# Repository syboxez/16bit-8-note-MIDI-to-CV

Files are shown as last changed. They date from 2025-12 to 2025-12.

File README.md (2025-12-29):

Multichannel MIDI to CV module by Craig Barnes and Andreas Oswald Hierzenberger
- Original project here: https://github.com/craigyjp/16bit-8-note-MIDI-to-CV

This project was originally designed as a proof of concept of an 8 channel 16-bit MIDI to CV module with autotune. This project has since been essentially deprecated in favor of Craig Branes's future projects, which you can find on his GitHub: https://github.com/craigyjp. Please do not ask for support with this project.

The KiCad schematics and Eurorack PCB can be found in the Hardware/schematics/kicad directory. Note that while the LFO module is not a part of the PCB, the schematics are still available in the same directory. The schematics include a change from +-15v to +-12v. This requires a 16 pin Eurorack power connector that includes a +5v power rail. A micro SD card should be inserted into the Teensy 4.1 to save settings.

The panel board uses DE-9 connectors as an easier patching method for polyphonic Eurorack-style patching up to eight voices. Converting between this connector and standard 3.5mm TS connectors is as simple as making a passive cable to do so. The pinout is as such:
Pins 1-8: Channels 1-8 respectively
Pin 9: Ground
- A PCB to make making an adapter more convenient is available here: https://gitlab.com/syboxez/de9-to-ts

All resistors and capacitors are 0805 SMD components, so this board can still be hand soldered.

TODO:
- Panel
- Build and Test

This project is licensed under the GNU GPL v3. A copy of the license is included in LICENSE.md. When redistributing, Craig Barnes and Andreas Oswald Hierzenberger MUST be mentioned, and a copy of the license must be included.

Original README below:
---

# 16bit-8-note-MIDI-to-CV

* Collaboration with Andreas Oswald "MrsColumbo" Hierzenberger

Newer version of my old 6 note poly CV converter, this time it uses 16 bit DACs and has the facility for autotune (not yet implemented). 

Using a teensy 4.1, the CV's, Pitchbend, CC, gates and triggers will all need some level conversion in hardware which I've covered in the schematic PDF. I've used matching 12k/36k resistors on the CV DAC level converters to give 4x conversion and this gives 1v/octave, Velocity uses 10k/10k for 2x conversion for 0-5v velocity range.

* The triggers and gates are currently +5v.
* 16 CV ouputs in 2 banks of 8 for osc1 & osc2 configurations
* 8 filter CV outputs
* 8 velocity CV outputs
* 8 gate outputs
* 8 trigger outputs
* Pitchbend, channel aftertouch and CC outputs
* Sustain pedal support over MIDI
* MIDI Channel selection or Omni
* Poly1, Poly2, Unison & Mono modes with note priority modes
* Polyphony variable from 2-8 notes, 1 note not required as you already have unison and mono.
* Transpose Mode +/- one Octave
* Octave shift 0 to -3 Octaves to give 0V on bottom C
* Oscillator 2 detune (CV outputs 9-16)
* Oscillator 2 interval settings 0-12 semitones (CV outputs 9-16)
* Up/Down/Select buttons for menu
* USB MIDI Host support as well as 5 pin DIN

# During the testing all the controls were done manually with pots and buttons, but to be integrated into a polysynth these functions need to be controlled over MIDI.

* MIDI CC numbers used to control functions

* CC 01  Modulation Wheel 0-12
* CC 14  VCO_B Interval. 0-127 (0-12 semitones)
* CC 15  VCO_B Detune. 0-12
* CC 16  PitchBend Depth. 0-127 (0-12 seimitones)
* CC 17  FM Mod Wheel Depth. 0-127
* CC 18  TM Mod Wheel Depth. 0-127
* CC 19  FM Aftertouch Depth. 0-127
* CC 20  TM Aftertouch Depth. 0-127
* CC 21  VCO_A Octave switch. (0-127) -1, 0, +1
* CC 22  VCO_B Octave switch. (0-127) -1, 0, +1
* CC 64  Sustain. 0-127  off < 63, on > 63
* CC 121 Start Autotune Routine.  start > 63
* CC 127 Keyboard Mode  0-127, Poly1, Poly2, Unison T,B,L, Mono T, B, L

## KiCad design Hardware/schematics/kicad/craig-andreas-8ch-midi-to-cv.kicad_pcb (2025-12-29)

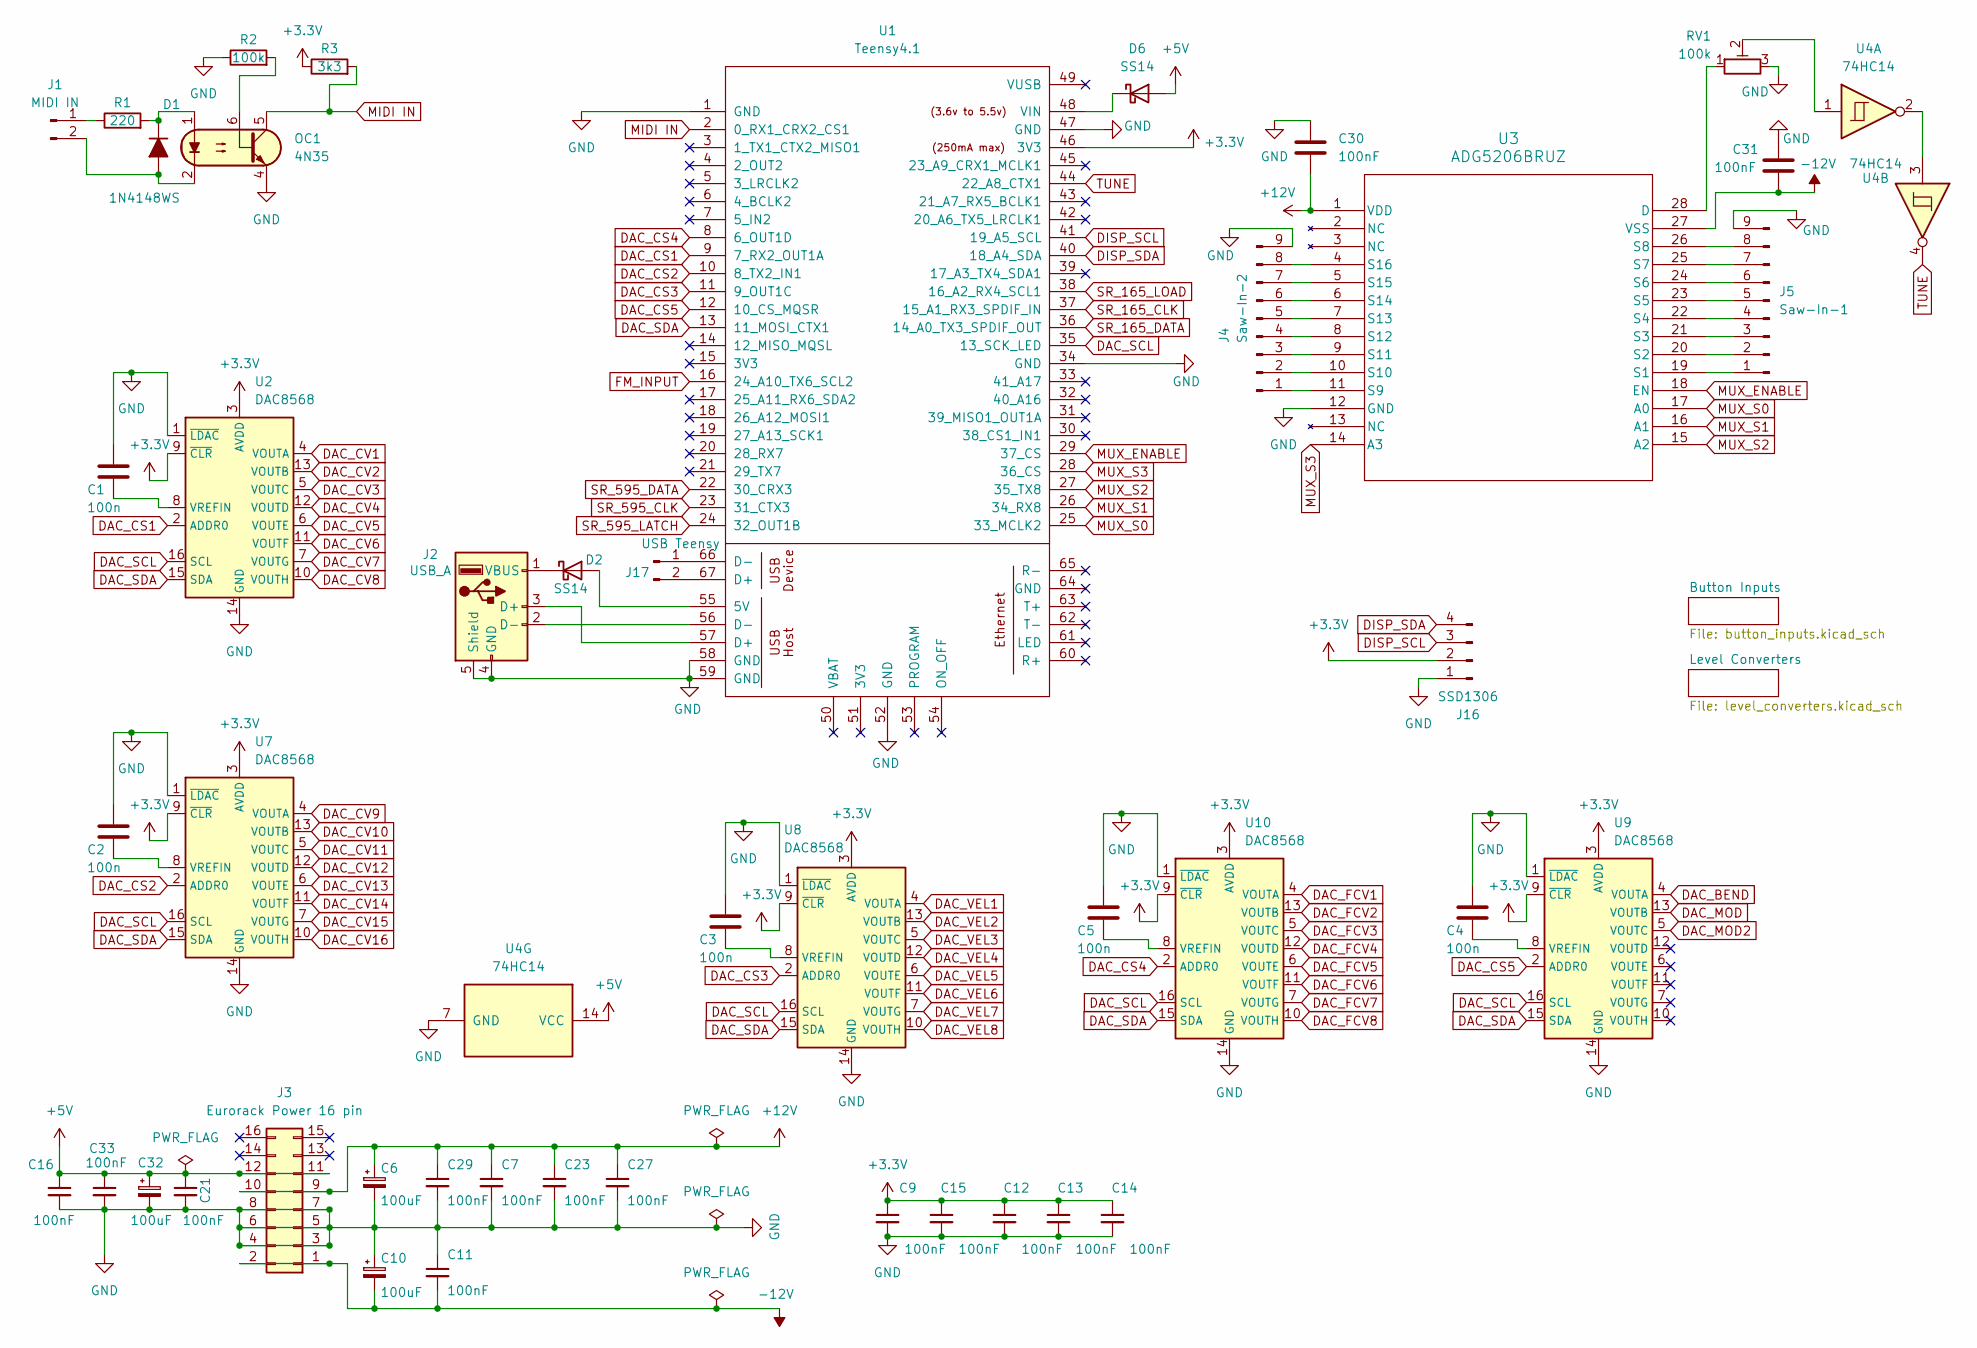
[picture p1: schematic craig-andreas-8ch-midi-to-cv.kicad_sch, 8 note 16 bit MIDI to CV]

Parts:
C1, C2, C3, C4, C5: 100n; C_0805_2012Metric_Pad1.18x1.45mm_HandSolder
C6, C10, C32: 100uF; CP_Radial_D8.0mm_P3.50mm
C7, C9, C11, C12, C13, C14, C15, C16, C21, C23, C27, C29, C30, C31, C33: 100nF; C_0805_2012Metric_Pad1.18x1.45mm_HandSolder
D1: 1N4148WS; D_SOD-323_HandSoldering
D2, D6: SS14; D_SMA_Handsoldering
J1: MIDI IN; JST_XH_B2B-XH-A_1x02_P2.50mm_Vertical
J2: USB_A; JST_XH_B3B-XH-A_1x03_P2.50mm_Vertical
J3: Eurorack Power 16 pin; IDC-Header_2x08_P2.54mm_Vertical
J4: Saw-In-2; JST_XH_B9B-XH-A_1x09_P2.50mm_Vertical
J5: Saw-In-1; JST_XH_B9B-XH-A_1x09_P2.50mm_Vertical
J16: SSD1306; JST_XH_B4B-XH-A_1x04_P2.50mm_Vertical
J17: USB Teensy; JST_XH_B2B-XH-A_1x02_P2.50mm_Vertical
OC1: 4N35; DIP-6_W7.62mm_LongPads
R1: 220; R_0805_2012Metric_Pad1.15x1.40mm_HandSolder
R2: 100k; R_0805_2012Metric_Pad1.15x1.40mm_HandSolder
R3: 3k3; R_0805_2012Metric_Pad1.15x1.40mm_HandSolder
RV1: 100k; Potentiometer_Runtron_RM-065_Vertical
U1: Teensy4.1; Teensy41
U2, U7, U8, U9, U10: DAC8568; TSSOP-16_4.4x5mm_P0.65mm
U3: ADG5206BRUZ; RU_28_ADI
U4: 74HC14; SOIC-14_3.9x8.7mm_P1.27mm

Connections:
+3.3V: C9.1, C12.1, C13.1, C14.1, C15.1, J16.2, R3.1, U1.46 (3V3), U2.3 (AVDD), U2.9 (~CLR), U7.3 (AVDD), U7.9 (~CLR), U8.3 (AVDD), U8.9 (~CLR), U9.3 (AVDD), U9.9 (~CLR), U10.3 (AVDD), U10.9 (~CLR); also elsewhere on the board
+5V: C16.1, C21.1, C32.1, C33.1, D6.2 (A), J3.11, J3.12, U4.14 (VCC); also elsewhere on the board
+12V: C6.1, C7.1, C23.1, C27.1, C29.1, C30.2, J3.9, J3.10, U3.1 (VDD); also elsewhere on the board
-12V: C10.2, C11.2, C31.1, J3.1, J3.2, U3.27 (VSS)
DAC_BEND: U9.4 (VOUTA); also elsewhere on the board
DAC_CS1: U1.9 (7_RX2_OUT1A), U2.2 (ADDR0)
DAC_CS2: U1.10 (8_TX2_IN1), U7.2 (ADDR0)
DAC_CS3: U1.11 (9_OUT1C), U8.2 (ADDR0)
DAC_CS4: U1.8 (6_OUT1D), U10.2 (ADDR0)
DAC_CS5: U1.12 (10_CS_MQSR), U9.2 (ADDR0)
DAC_CV1: U2.4 (VOUTA); also elsewhere on the board
DAC_CV2: U2.13 (VOUTB); also elsewhere on the board
DAC_CV3: U2.5 (VOUTC); also elsewhere on the board
DAC_CV4: U2.12 (VOUTD); also elsewhere on the board
DAC_CV5: U2.6 (VOUTE); also elsewhere on the board
DAC_CV6: U2.11 (VOUTF); also elsewhere on the board
DAC_CV7: U2.7 (VOUTG); also elsewhere on the board
DAC_CV8: U2.10 (VOUTH); also elsewhere on the board
DAC_CV9: U7.4 (VOUTA); also elsewhere on the board
DAC_CV10: U7.13 (VOUTB); also elsewhere on the board
DAC_CV11: U7.5 (VOUTC); also elsewhere on the board
DAC_CV12: U7.12 (VOUTD); also elsewhere on the board
DAC_CV13: U7.6 (VOUTE); also elsewhere on the board
DAC_CV14: U7.11 (VOUTF); also elsewhere on the board
DAC_CV15: U7.7 (VOUTG); also elsewhere on the board
DAC_CV16: U7.10 (VOUTH); also elsewhere on the board
DAC_FCV1: U10.4 (VOUTA); also elsewhere on the board
DAC_FCV2: U10.13 (VOUTB); also elsewhere on the board
DAC_FCV3: U10.5 (VOUTC); also elsewhere on the board
DAC_FCV4: U10.12 (VOUTD); also elsewhere on the board
DAC_FCV5: U10.6 (VOUTE); also elsewhere on the board
DAC_FCV6: U10.11 (VOUTF); also elsewhere on the board
DAC_FCV7: U10.7 (VOUTG); also elsewhere on the board
DAC_FCV8: U10.10 (VOUTH); also elsewhere on the board
DAC_MOD: U9.13 (VOUTB); also elsewhere on the board
DAC_MOD2: U9.5 (VOUTC); also elsewhere on the board
DAC_SCL: U1.35 (13_SCK_LED), U2.16 (SCL), U7.16 (SCL), U8.16 (SCL), U9.16 (SCL), U10.16 (SCL)
DAC_SDA: U1.13 (11_MOSI_CTX1), U2.15 (SDA), U7.15 (SDA), U8.15 (SDA), U9.15 (SDA), U10.15 (SDA)
DAC_VEL1: U8.4 (VOUTA); also elsewhere on the board
DAC_VEL2: U8.13 (VOUTB); also elsewhere on the board
DAC_VEL3: U8.5 (VOUTC); also elsewhere on the board
DAC_VEL4: U8.12 (VOUTD); also elsewhere on the board
DAC_VEL5: U8.6 (VOUTE); also elsewhere on the board
DAC_VEL6: U8.11 (VOUTF); also elsewhere on the board
DAC_VEL7: U8.7 (VOUTG); also elsewhere on the board
DAC_VEL8: U8.10 (VOUTH); also elsewhere on the board
DISP_SCL: J16.3, U1.41 (19_A5_SCL)
DISP_SDA: J16.4, U1.40 (18_A4_SDA)
FM_INPUT: U1.16 (24_A10_TX6_SCL2)
GND: C1.1, C2.1, C3.1, C4.1, C5.1, C6.2, C7.2, C9.2, C10.1, C11.1, C12.2, C13.2, C14.2, C15.2, C16.2, C21.2, C23.2, C27.2, C29.2, C30.1, C31.2, C32.2, C33.2, J2.4 (GND), J2.5 (Shield), J3.3, J3.4, J3.5, J3.6, J3.7, J3.8, J4.9, J5.9, J16.1, OC1.4, R2.1, RV1.3, U1.1 (GND), U1.34 (GND), U1.47 (GND), U1.52 (GND), U1.58 (GND), U1.59 (GND), U2.1 (~LDAC), U2.14 (GND), U3.12 (GND), U4.7 (GND), U7.1 (~LDAC), U7.14 (GND), U8.1 (~LDAC), U8.14 (GND), U9.1 (~LDAC), U9.14 (GND), U10.1 (~LDAC), U10.14 (GND); also elsewhere on the board
MIDI IN: OC1.5, R3.2, U1.2 (0_RX1_CRX2_CS1)
MUX_ENABLE: U1.29 (37_CS), U3.18 (EN)
MUX_S0: U1.25 (33_MCLK2), U3.17 (A0)
MUX_S1: U1.26 (34_RX8), U3.16 (A1)
MUX_S2: U1.27 (35_TX8), U3.15 (A2)
MUX_S3: U1.28 (36_CS), U3.14 (A3)
unnamed: D1.2 (A), J1.2, OC1.2
unnamed: D1.1 (K), OC1.1, R1.2
unnamed: D2.2 (A), U1.55 (5V)
unnamed: D2.1 (K), J2.1 (VBUS)
unnamed: D6.1 (K), U1.48 (VIN)
unnamed: J1.1, R1.1
unnamed: J2.3 (D+), U1.57 (D+)
unnamed: J2.2 (D-), U1.56 (D-)
unnamed: J4.1, U3.11 (S9)
unnamed: J4.2, U3.10 (S10)
unnamed: J4.3, U3.9 (S11)
unnamed: J4.4, U3.8 (S12)
unnamed: J4.5, U3.7 (S13)
unnamed: J4.6, U3.6 (S14)
unnamed: J4.7, U3.5 (S15)
unnamed: J4.8, U3.4 (S16)
unnamed: J5.1, U3.19 (S1)
unnamed: J5.2, U3.20 (S2)
unnamed: J5.3, U3.21 (S3)
unnamed: J5.4, U3.22 (S4)
unnamed: J5.5, U3.23 (S5)
unnamed: J5.6, U3.24 (S6)
unnamed: J5.7, U3.25 (S7)
unnamed: J5.8, U3.26 (S8)
unnamed: J17.1, U1.66 (D-)
unnamed: J17.2, U1.67 (D+)
unnamed: OC1.6, R2.2
unnamed: RV1.2, U4.1
unnamed: C1.2, U2.8 (VREFIN)
unnamed: RV1.1, U3.28 (D)
unnamed: U4.2, U4.3
unnamed: C2.2, U7.8 (VREFIN)
unnamed: C3.2, U8.8 (VREFIN)
unnamed: C4.2, U9.8 (VREFIN)
unnamed: C5.2, U10.8 (VREFIN)
SR_165_CLK: U1.37 (15_A1_RX3_SPDIF_IN); also elsewhere on the board
SR_165_DATA: U1.36 (14_A0_TX3_SPDIF_OUT); also elsewhere on the board
SR_165_LOAD: U1.38 (16_A2_RX4_SCL1); also elsewhere on the board
SR_595_CLK: U1.23 (31_CTX3); also elsewhere on the board
SR_595_DATA: U1.22 (30_CRX3); also elsewhere on the board
SR_595_LATCH: U1.24 (32_OUT1B); also elsewhere on the board
TUNE: U1.44 (22_A8_CTX1), U4.4

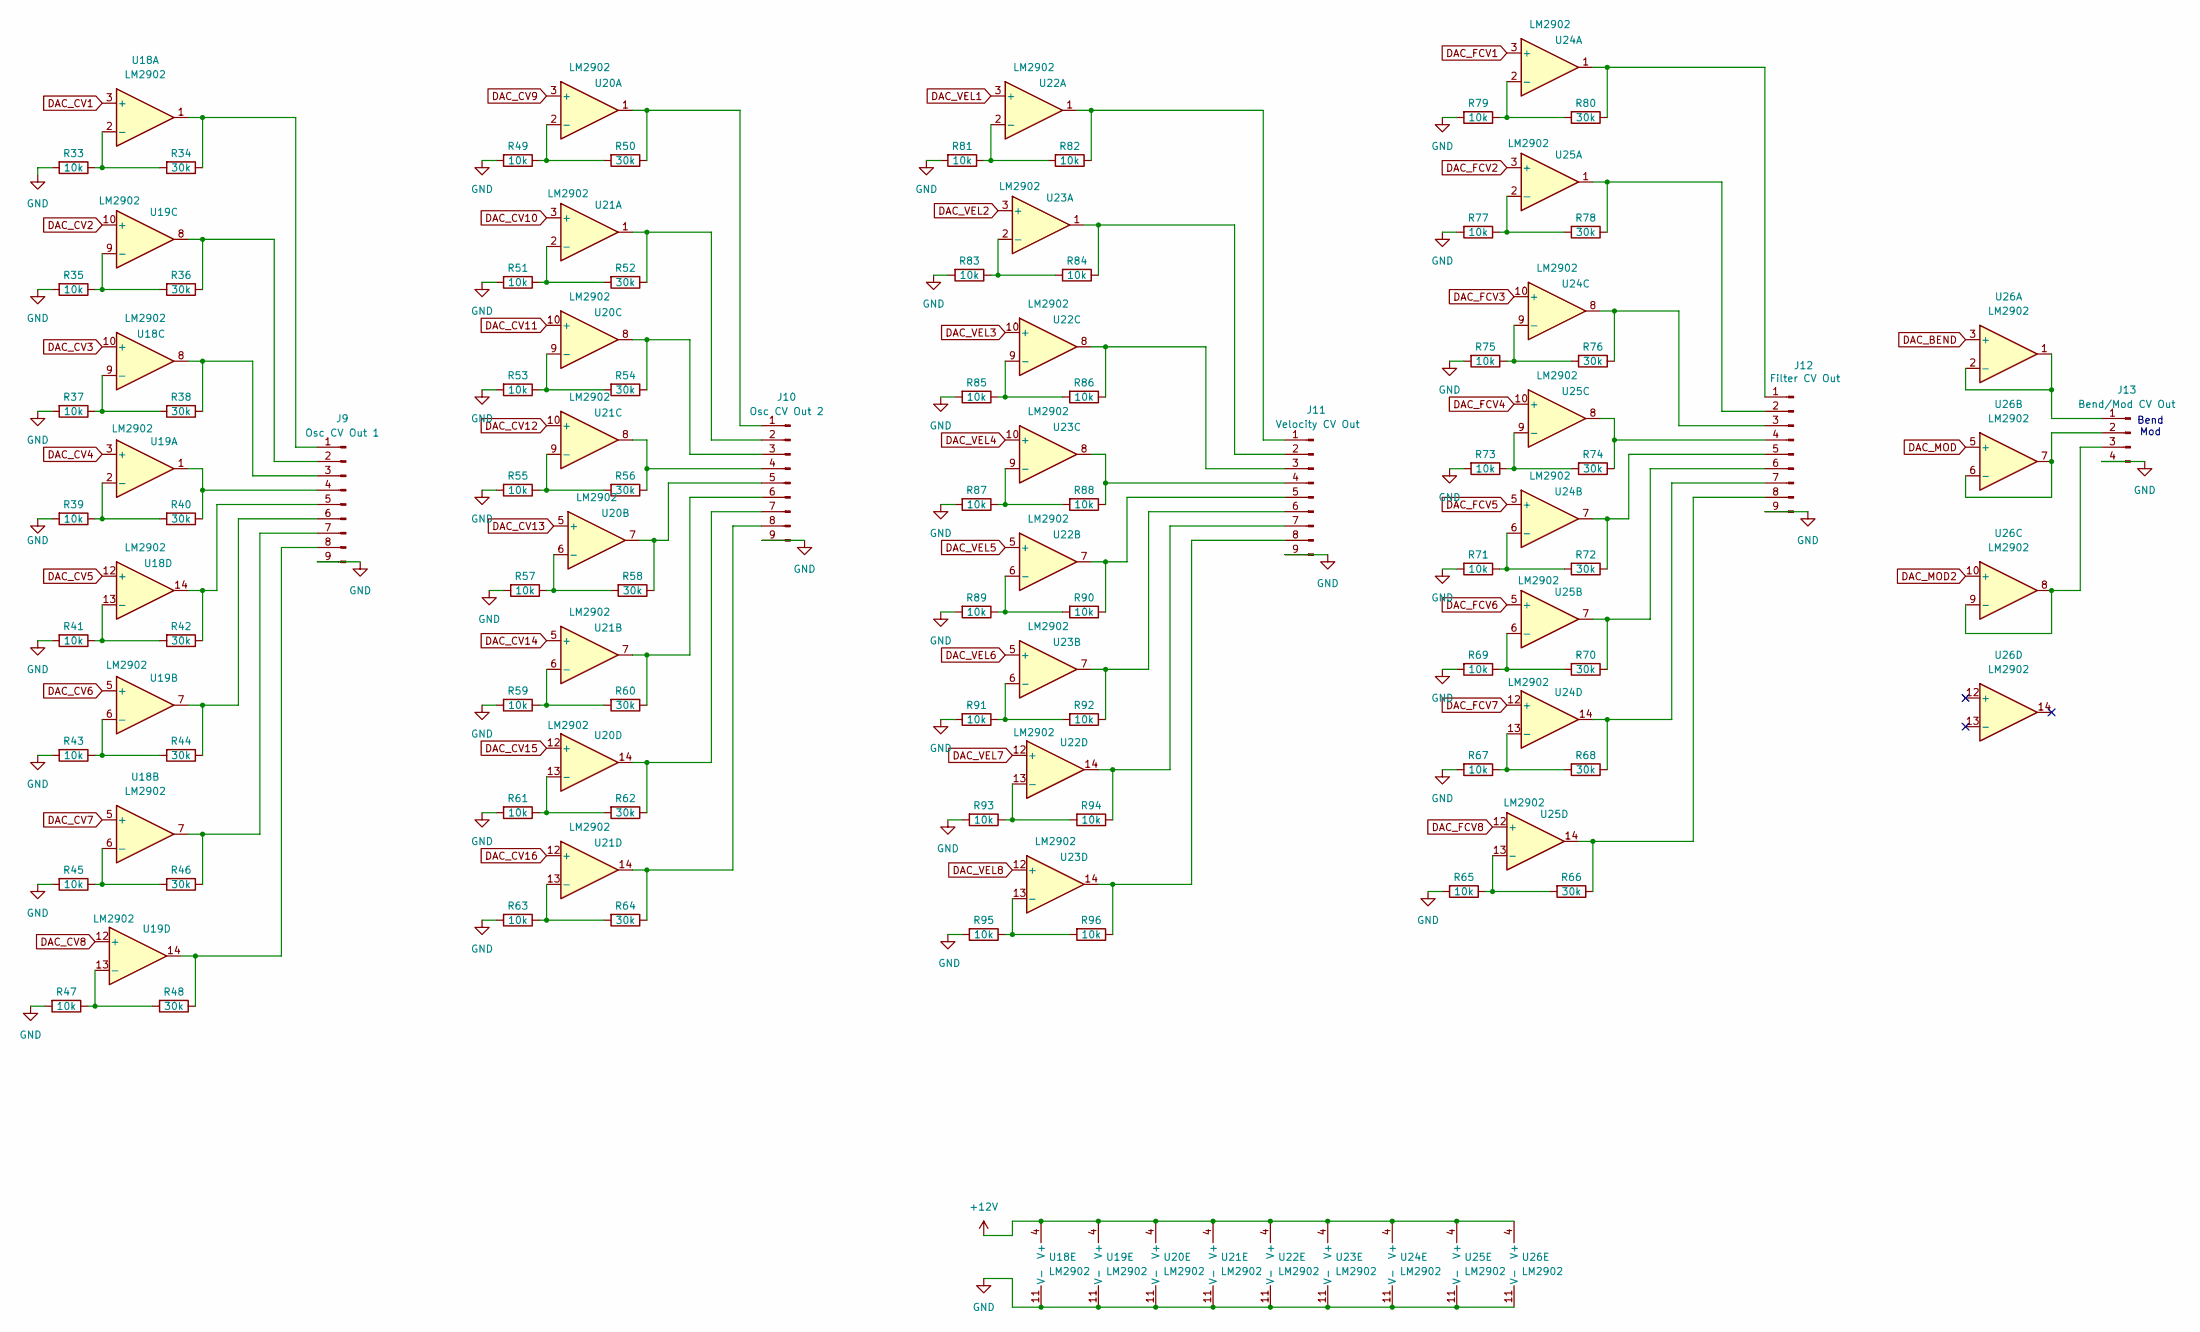
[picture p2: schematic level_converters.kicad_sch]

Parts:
J9: Osc CV Out 1; IDC-Header_2x05_P2.54mm_Vertical
J10: Osc CV Out 2; IDC-Header_2x05_P2.54mm_Vertical
J11: Velocity CV Out; IDC-Header_2x05_P2.54mm_Vertical
J12: Filter CV Out; JST_XH_B9B-XH-A_1x09_P2.50mm_Vertical
J13: Bend/Mod CV Out; JST_XH_B4B-XH-A_1x04_P2.50mm_Vertical
R33, R35, R37, R39, R41, R43, R45, R47, R49, R51, R53, R55, R57, R59, R61, R63, R65, R67, R69, R71, R73, R75, R77, R79, R81, R82, R83, R84, R85, R86, R87, R88, R89, R90, R91, R92, R93, R94, R95, R96: 10k; R_0805_2012Metric_Pad1.15x1.40mm_HandSolder
R34, R36, R38, R40, R42, R44, R46, R48, R50, R52, R54, R56, R58, R60, R62, R64, R66, R68, R70, R72, R74, R76, R78, R80: 30k; R_0805_2012Metric_Pad1.15x1.40mm_HandSolder
U18, U19, U20, U21, U22, U23, U24, U25, U26: LM2902; SOIC-14_3.9x8.7mm_P1.27mm

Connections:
+12V: U18.4 (V+), U19.4 (V+), U20.4 (V+), U21.4 (V+), U22.4 (V+), U23.4 (V+), U24.4 (V+), U25.4 (V+), U26.4 (V+); also elsewhere on the board
DAC_BEND: U26.3 (+); also elsewhere on the board
DAC_CV1: U18.3 (+); also elsewhere on the board
DAC_CV2: U19.10 (+); also elsewhere on the board
DAC_CV3: U18.10 (+); also elsewhere on the board
DAC_CV4: U19.3 (+); also elsewhere on the board
DAC_CV5: U18.12 (+); also elsewhere on the board
DAC_CV6: U19.5 (+); also elsewhere on the board
DAC_CV7: U18.5 (+); also elsewhere on the board
DAC_CV8: U19.12 (+); also elsewhere on the board
DAC_CV9: U20.3 (+); also elsewhere on the board
DAC_CV10: U21.3 (+); also elsewhere on the board
DAC_CV11: U20.10 (+); also elsewhere on the board
DAC_CV12: U21.10 (+); also elsewhere on the board
DAC_CV13: U20.5 (+); also elsewhere on the board
DAC_CV14: U21.5 (+); also elsewhere on the board
DAC_CV15: U20.12 (+); also elsewhere on the board
DAC_CV16: U21.12 (+); also elsewhere on the board
DAC_FCV1: U24.3 (+); also elsewhere on the board
DAC_FCV2: U25.3 (+); also elsewhere on the board
DAC_FCV3: U24.10 (+); also elsewhere on the board
DAC_FCV4: U25.10 (+); also elsewhere on the board
DAC_FCV5: U24.5 (+); also elsewhere on the board
DAC_FCV6: U25.5 (+); also elsewhere on the board
DAC_FCV7: U24.12 (+); also elsewhere on the board
DAC_FCV8: U25.12 (+); also elsewhere on the board
DAC_MOD: U26.5 (+); also elsewhere on the board
DAC_MOD2: U26.10 (+); also elsewhere on the board
DAC_VEL1: U22.3 (+); also elsewhere on the board
DAC_VEL2: U23.3 (+); also elsewhere on the board
DAC_VEL3: U22.10 (+); also elsewhere on the board
DAC_VEL4: U23.10 (+); also elsewhere on the board
DAC_VEL5: U22.5 (+); also elsewhere on the board
DAC_VEL6: U23.5 (+); also elsewhere on the board
DAC_VEL7: U22.12 (+); also elsewhere on the board
DAC_VEL8: U23.12 (+); also elsewhere on the board
GND: J9.9, J9.10, J10.9, J10.10, J11.9, J11.10, J12.9, J13.4, R33.2, R35.2, R37.2, R39.2, R41.2, R43.2, R45.2, R47.2, R49.2, R51.2, R53.2, R55.2, R57.2, R59.2, R61.2, R63.2, R65.2, R67.2, R69.2, R71.2, R73.2, R75.2, R77.2, R79.2, R81.2, R83.2, R85.2, R87.2, R89.2, R91.2, R93.2, R95.2, U18.11 (V-), U19.11 (V-), U20.11 (V-), U21.11 (V-), U22.11 (V-), U23.11 (V-), U24.11 (V-), U25.11 (V-), U26.11 (V-); also elsewhere on the board
unnamed: J9.1, R34.1, U18.1
unnamed: J9.2, R36.1, U19.8
unnamed: J9.3, R38.1, U18.8
unnamed: J9.4, R40.1, U19.1
unnamed: J9.5, R42.1, U18.14
unnamed: J9.6, R44.1, U19.7
unnamed: J9.7, R46.1, U18.7
unnamed: J9.8, R48.1, U19.14
unnamed: J10.1, R50.1, U20.1
unnamed: J10.2, R52.1, U21.1
unnamed: J10.3, R54.1, U20.8
unnamed: J10.4, R56.1, U21.8
unnamed: J10.5, R58.1, U20.7
unnamed: J10.6, R60.1, U21.7
unnamed: J10.7, R62.1, U20.14
unnamed: J10.8, R64.1, U21.14
unnamed: J11.1, R82.1, U22.1
unnamed: J11.2, R84.1, U23.1
unnamed: J11.3, R86.1, U22.8
unnamed: J11.4, R88.1, U23.8
unnamed: J11.5, R90.1, U22.7
unnamed: J11.6, R92.1, U23.7
unnamed: J11.7, R94.1, U22.14
unnamed: J11.8, R96.1, U23.14
unnamed: J12.1, R80.1, U24.1
unnamed: J12.2, R78.1, U25.1
unnamed: J12.3, R76.1, U24.8
unnamed: J12.4, R74.1, U25.8
unnamed: J12.5, R72.1, U24.7
unnamed: J12.6, R70.1, U25.7
unnamed: J12.7, R68.1, U24.14
unnamed: J12.8, R66.1, U25.14
unnamed: J13.1, U26.1, U26.2 (-)
unnamed: J13.2, U26.6 (-), U26.7
unnamed: J13.3, U26.8, U26.9 (-)
unnamed: R33.1, R34.2, U18.2 (-)
unnamed: R45.1, R46.2, U18.6 (-)
unnamed: R37.1, R38.2, U18.9 (-)
unnamed: R41.1, R42.2, U18.13 (-)
unnamed: R39.1, R40.2, U19.2 (-)
unnamed: R43.1, R44.2, U19.6 (-)
unnamed: R35.1, R36.2, U19.9 (-)
unnamed: R47.1, R48.2, U19.13 (-)
unnamed: R49.1, R50.2, U20.2 (-)
unnamed: R57.1, R58.2, U20.6 (-)
unnamed: R53.1, R54.2, U20.9 (-)
unnamed: R61.1, R62.2, U20.13 (-)
unnamed: R51.1, R52.2, U21.2 (-)
unnamed: R59.1, R60.2, U21.6 (-)
unnamed: R55.1, R56.2, U21.9 (-)
unnamed: R63.1, R64.2, U21.13 (-)
unnamed: R81.1, R82.2, U22.2 (-)
unnamed: R89.1, R90.2, U22.6 (-)
unnamed: R85.1, R86.2, U22.9 (-)
unnamed: R93.1, R94.2, U22.13 (-)
unnamed: R83.1, R84.2, U23.2 (-)
unnamed: R91.1, R92.2, U23.6 (-)
unnamed: R87.1, R88.2, U23.9 (-)
unnamed: R95.1, R96.2, U23.13 (-)
unnamed: R79.1, R80.2, U24.2 (-)
unnamed: R71.1, R72.2, U24.6 (-)
unnamed: R75.1, R76.2, U24.9 (-)
unnamed: R67.1, R68.2, U24.13 (-)
unnamed: R77.1, R78.2, U25.2 (-)
unnamed: R69.1, R70.2, U25.6 (-)
unnamed: R73.1, R74.2, U25.9 (-)
unnamed: R65.1, R66.2, U25.13 (-)

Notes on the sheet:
Bend Mod

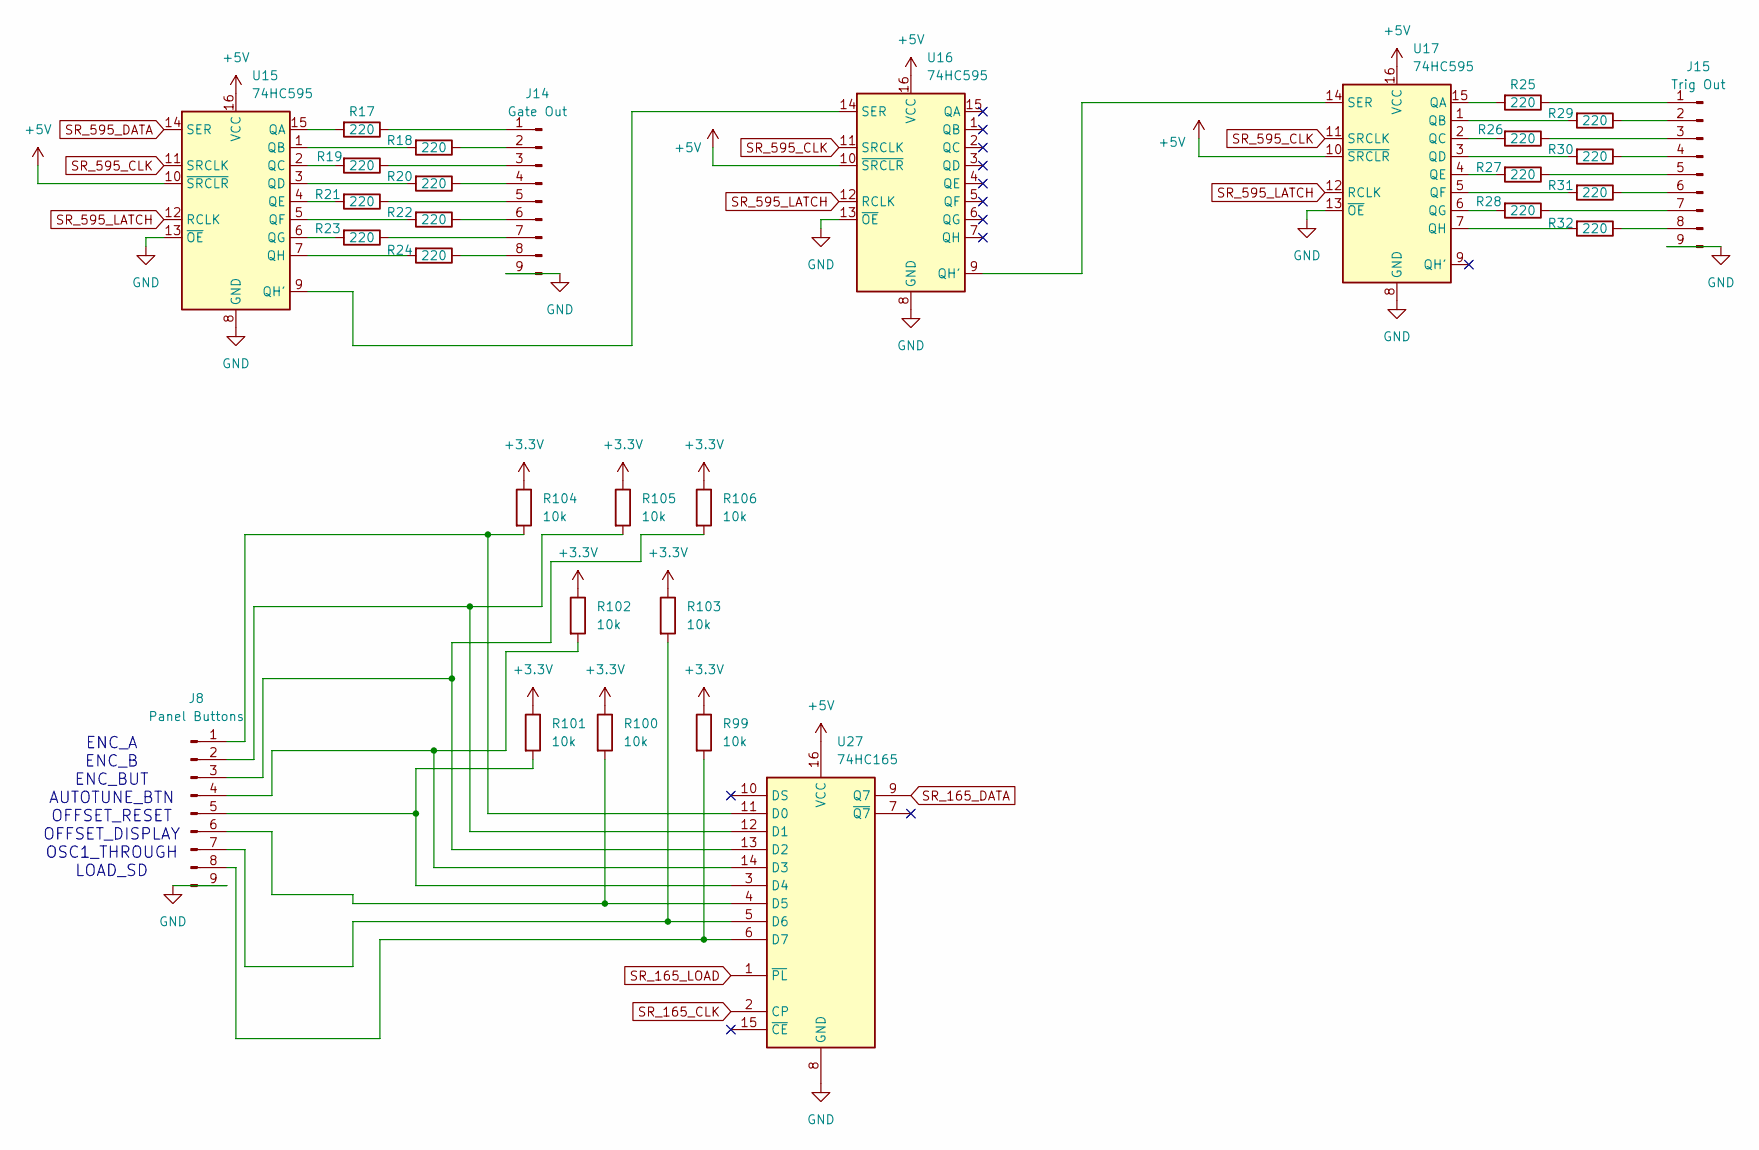
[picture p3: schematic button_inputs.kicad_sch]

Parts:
J8: Panel Buttons; JST_XH_B9B-XH-A_1x09_P2.50mm_Vertical
J14: Gate Out; JST_XH_B9B-XH-A_1x09_P2.50mm_Vertical
J15: Trig Out; JST_XH_B9B-XH-A_1x09_P2.50mm_Vertical
R17, R18, R19, R20, R21, R22, R23, R24, R25, R26, R27, R28, R29, R30, R31, R32: 220; R_0805_2012Metric_Pad1.15x1.40mm_HandSolder
R99, R100, R101, R102, R103, R104, R105, R106: 10k; R_0805_2012Metric_Pad1.15x1.40mm_HandSolder
U15, U16, U17: 74HC595; SOIC-16_3.9x9.9mm_P1.27mm
U27: 74HC165; SOIC-16_3.9x9.9mm_P1.27mm

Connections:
+3.3V: R99.1, R100.1, R101.1, R102.1, R103.1, R104.1, R105.1, R106.1; also elsewhere on the board
+5V: U15.10 (~SRCLR), U15.16 (VCC), U16.10 (~SRCLR), U16.16 (VCC), U17.10 (~SRCLR), U17.16 (VCC), U27.16 (VCC); also elsewhere on the board
GND: J8.9, J14.9, J15.9, U15.8 (GND), U15.13 (~OE), U16.8 (GND), U16.13 (~OE), U17.8 (GND), U17.13 (~OE), U27.8 (GND); also elsewhere on the board
unnamed: J8.1, R104.2, U27.11 (D0)
unnamed: J8.2, R105.2, U27.12 (D1)
unnamed: J8.3, R106.2, U27.13 (D2)
unnamed: J8.4, R102.2, U27.14 (D3)
unnamed: J8.5, R101.2, U27.3 (D4)
unnamed: J8.6, R100.2, U27.4 (D5)
unnamed: J8.7, R103.2, U27.5 (D6)
unnamed: J8.8, R99.2, U27.6 (D7)
unnamed: J14.1, R17.1
unnamed: J14.2, R18.1
unnamed: J14.3, R19.1
unnamed: J14.4, R20.1
unnamed: J14.5, R21.1
unnamed: J14.6, R22.1
unnamed: J14.7, R23.1
unnamed: J14.8, R24.1
unnamed: J15.1, R25.1
unnamed: J15.2, R29.1
unnamed: J15.3, R26.1
unnamed: J15.4, R30.1
unnamed: J15.5, R27.1
unnamed: J15.6, R31.1
unnamed: J15.7, R28.1
unnamed: J15.8, R32.1
unnamed: R17.2, U15.15 (QA)
unnamed: R18.2, U15.1 (QB)
unnamed: R19.2, U15.2 (QC)
unnamed: R20.2, U15.3 (QD)
unnamed: R21.2, U15.4 (QE)
unnamed: R22.2, U15.5 (QF)
unnamed: R23.2, U15.6 (QG)
unnamed: U15.9 (QH'), U16.14 (SER)
unnamed: R24.2, U15.7 (QH)
unnamed: U16.9 (QH'), U17.14 (SER)
unnamed: R25.2, U17.15 (QA)
unnamed: R29.2, U17.1 (QB)
unnamed: R26.2, U17.2 (QC)
unnamed: R30.2, U17.3 (QD)
unnamed: R27.2, U17.4 (QE)
unnamed: R31.2, U17.5 (QF)
unnamed: R28.2, U17.6 (QG)
unnamed: R32.2, U17.7 (QH)
SR_165_CLK: U27.2 (CP); also elsewhere on the board
SR_165_DATA: U27.9 (Q7); also elsewhere on the board
SR_165_LOAD: U27.1 (~PL); also elsewhere on the board
SR_595_CLK: U15.11 (SRCLK), U16.11 (SRCLK), U17.11 (SRCLK); also elsewhere on the board
SR_595_DATA: U15.14 (SER); also elsewhere on the board
SR_595_LATCH: U15.12 (RCLK), U16.12 (RCLK), U17.12 (RCLK); also elsewhere on the board

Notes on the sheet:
ENC_A ENC_B ENC_BUT AUTOTUNE_BTN OFFSET_RESET OFFSET_DISPLAY OSC1_THROUGH LOAD_SD

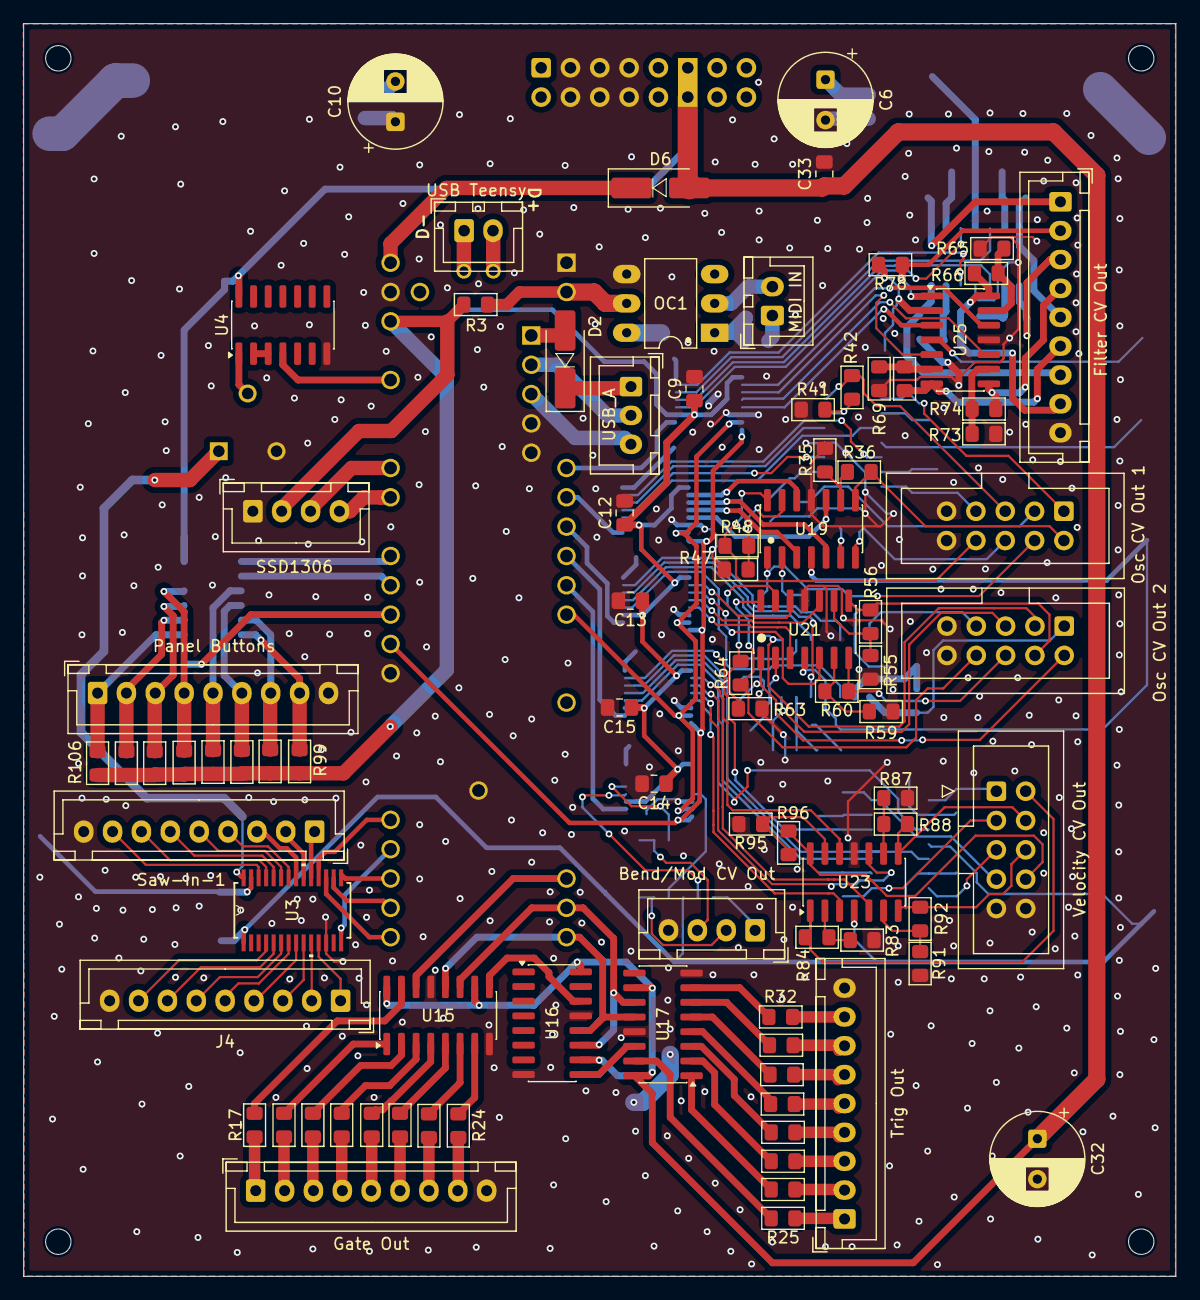
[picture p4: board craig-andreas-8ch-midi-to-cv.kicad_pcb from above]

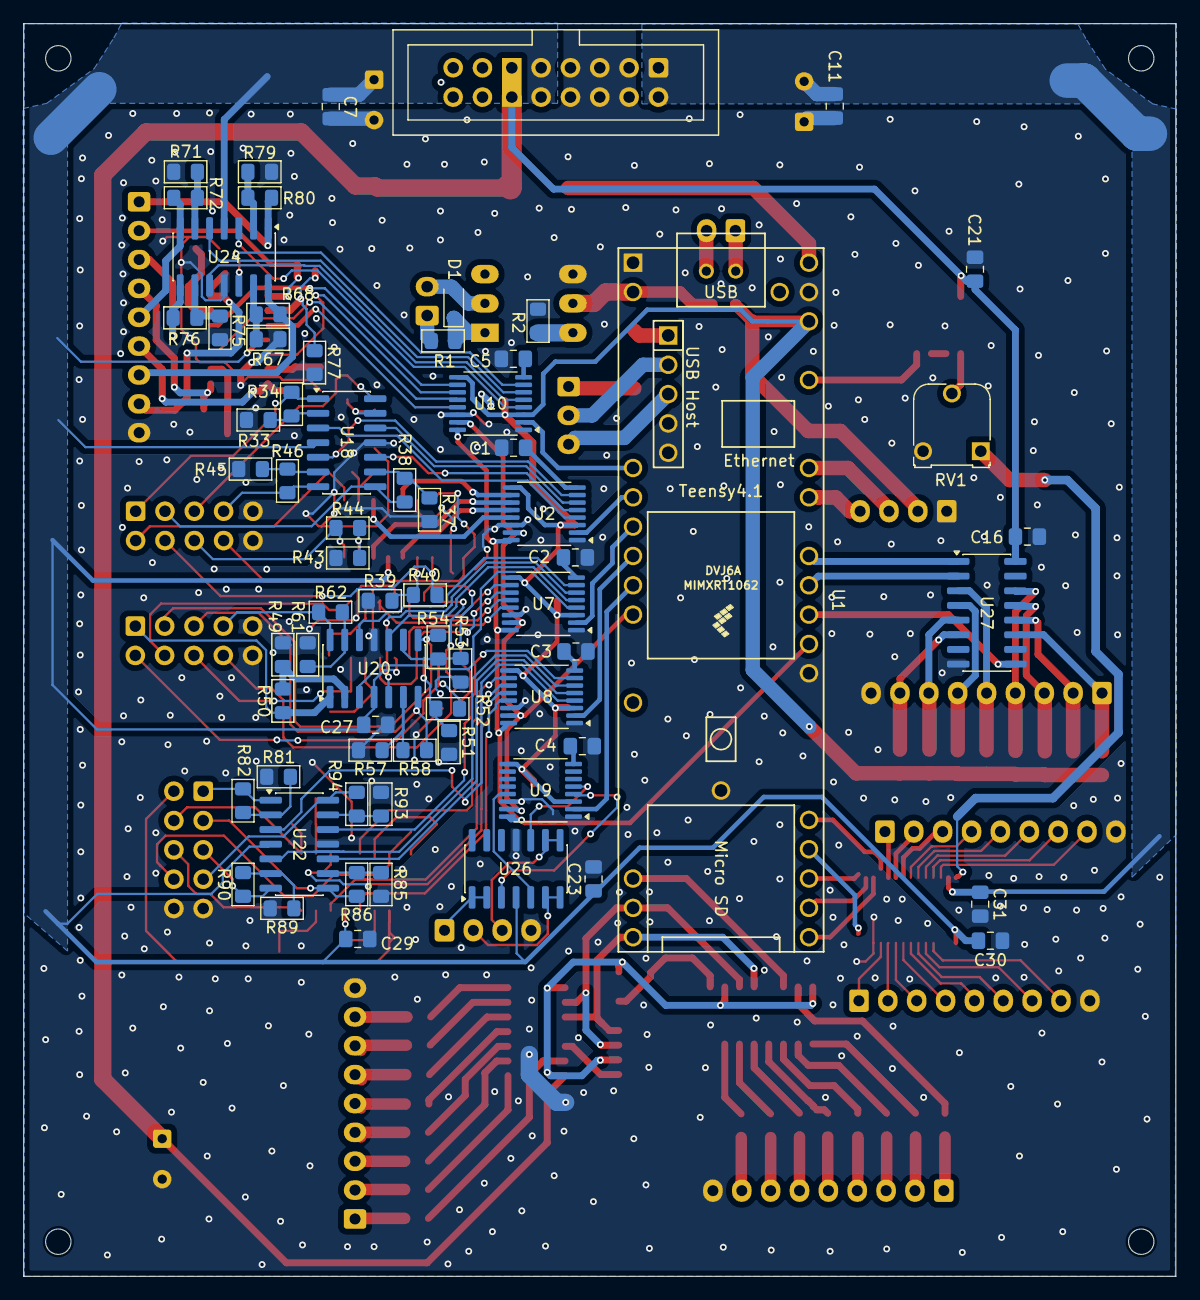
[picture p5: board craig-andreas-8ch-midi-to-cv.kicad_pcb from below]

Board: 2 copper layers, 99.8 x 108.5 mm, 155 parts (68 on the bottom side), 206 nets.

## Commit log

2025-11-14 Add KiCAD schematics created using PDF schematics as a reference
    [button_inputs.kicad_sch, craig-andreas-8ch-midi-to-cv.kicad_pcb, craig-andreas-8ch-midi-to-cv.kicad_sch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]
2025-11-14 Add 3.3v pull-up resistors to buttons
    [button_inputs.kicad_sch]
2025-12-21 Modify schematics to suit a complete Eurorack PCB design
    [button_inputs.kicad_sch, craig-andreas-8ch-midi-to-cv.kicad_pcb, craig-andreas-8ch-midi-to-cv.kicad_sch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]
2025-12-22 Fix schematic bug
    [level_converters.kicad_sch, lfo.kicad_sch]
2025-12-29 Remove LFO in favor of standalone LFO and create PCB. FM Input still exists in case it's needed.
    [craig-andreas-8ch-midi-to-cv.kicad_pcb, craig-andreas-8ch-midi-to-cv.kicad_sch, level_converters.kicad_sch]
